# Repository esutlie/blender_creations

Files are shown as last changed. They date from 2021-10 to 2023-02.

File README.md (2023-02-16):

<h3 align="center">Blender Creations</h3>
  <p align="center">
    Create custom 3D printed pieces for behavior boxes and headcap implants.
  </p>
</div>

<!-- ABOUT THE PROJECT -->
## About The Project

Create and export blender meshes for 3D printing. Headcap builds are for Neuropixel 2.0 probes. Assembly and surgury protocol for implantation in mice will be published in a future methods paper. Chamber builds are for the behavior boxes used in the Shuler lab.

<!-- GETTING STARTED -->
## Installation

1. Clone the repo
   ```sh
   git clone https://github.com/esutlie/blender_creations.git
   ```
2. Selecet pieces to generate in main.py (dimentions an be adjusted in builds.py)
3. Select call_file_win.py in the blender file viewer and click run

<!-- LICENSE -->
## License

Distributed under the MIT License. See `LICENSE.txt` for more information.

<!-- CONTACT -->
## Contact

Elissa Sutlief - elissasutlief@gmail.com

Project Link: [https://github.com/esutlie/behavior_code](https://github.com/esutlie/behavior_code)

<p align="right">(<a href="#readme-top">back to top</a>)</p>

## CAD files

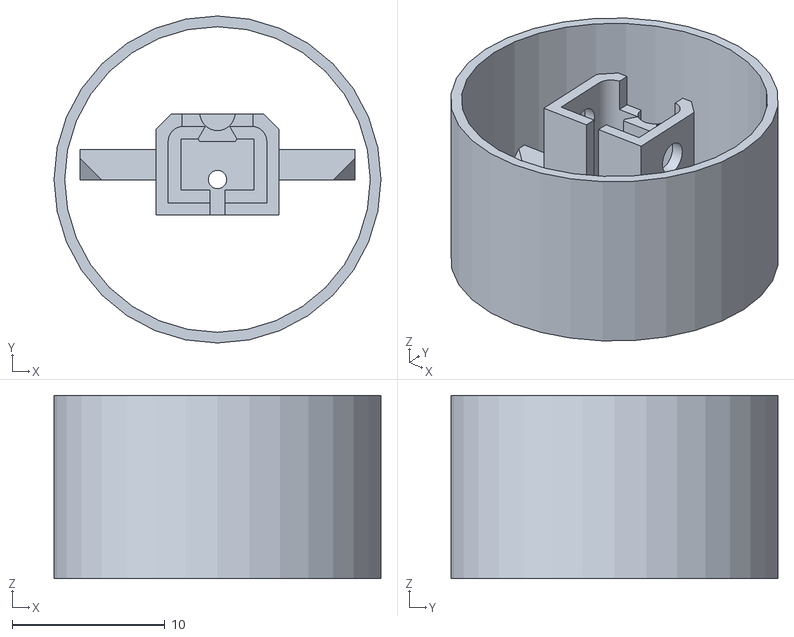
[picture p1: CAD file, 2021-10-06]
blender/stlexports/2021-09-28_10-52-53/cap.stl
21.4 x 21.4 x 12.0

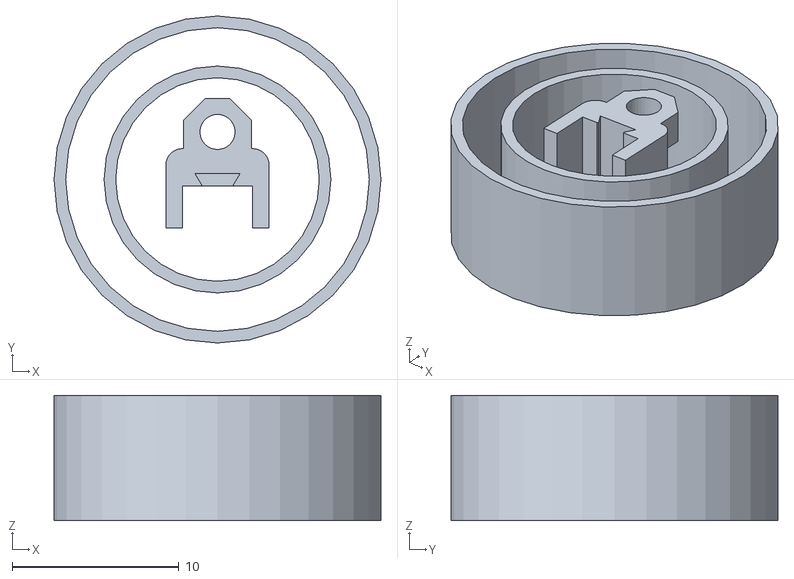
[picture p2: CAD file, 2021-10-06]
blender/stlexports/2021-09-29_13-45-59/holder.stl
19.6 x 19.6 x 7.50

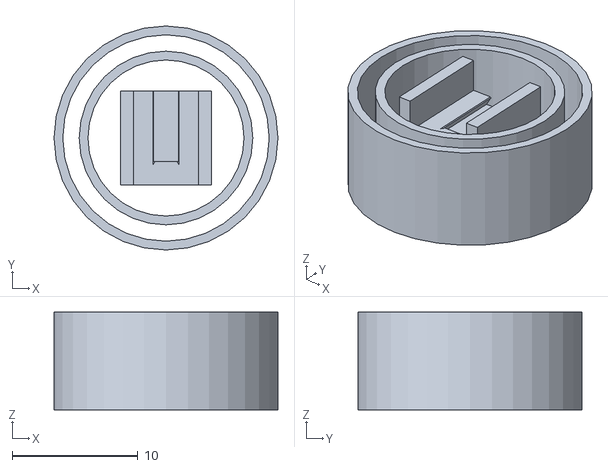
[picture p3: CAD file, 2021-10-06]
blender/stlexports/2021-09-30_14-25-20/holder.stl
17.8 x 17.8 x 7.75

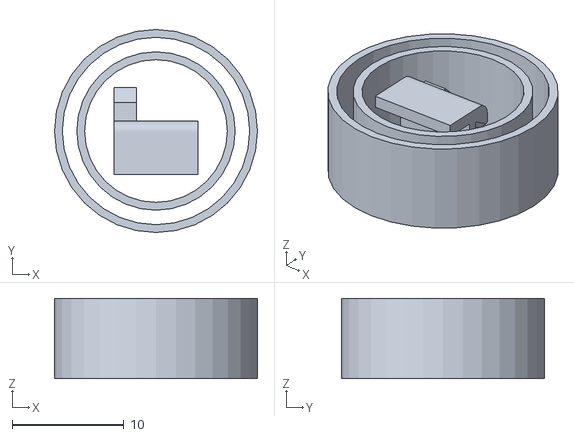
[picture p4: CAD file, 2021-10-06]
blender/stlexports/2021-09-30_14-29-47/holder.stl
18.2 x 18.2 x 7.20

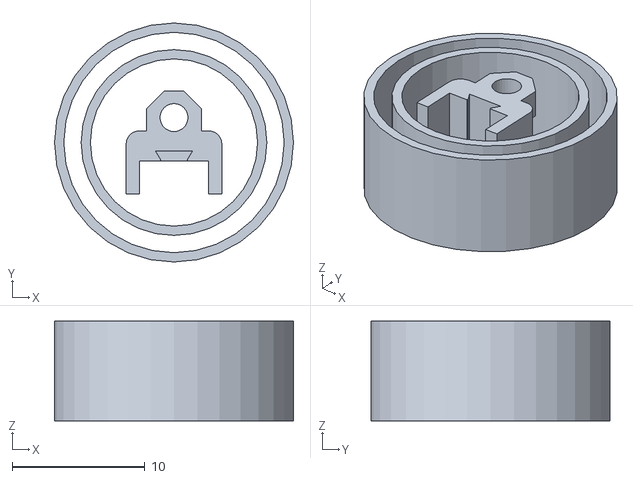
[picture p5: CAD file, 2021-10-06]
blender/stlexports/2021-09-30_14-30-03/holder.stl
18.0 x 18.0 x 7.50

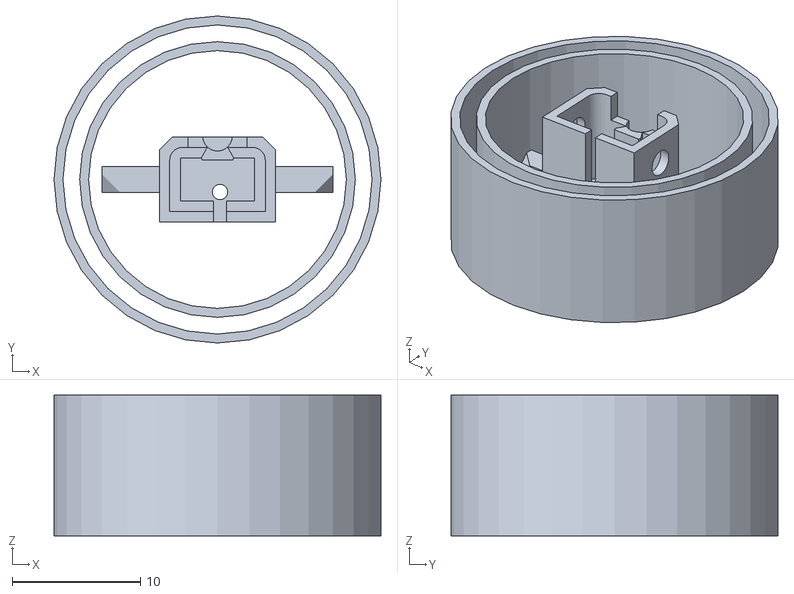
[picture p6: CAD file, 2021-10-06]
blender/stlexports/2021-10-01_13-02-37/cap.stl
25.5 x 25.5 x 11.0

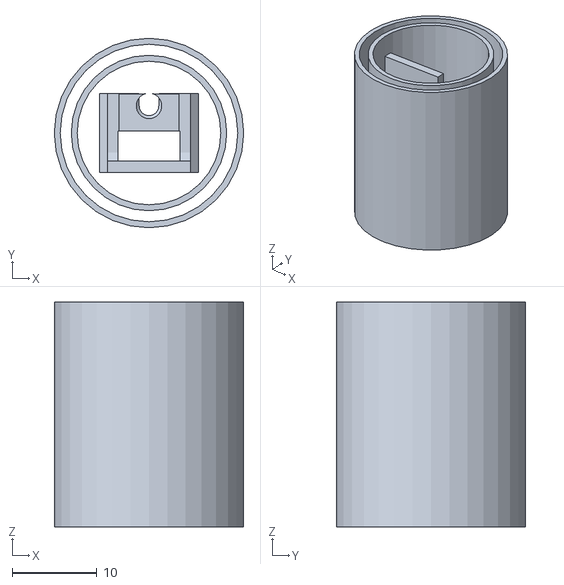
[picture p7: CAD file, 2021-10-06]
blender/stlexports/2021-10-04_15-12-39/cover.stl
22.3 x 22.3 x 26.5

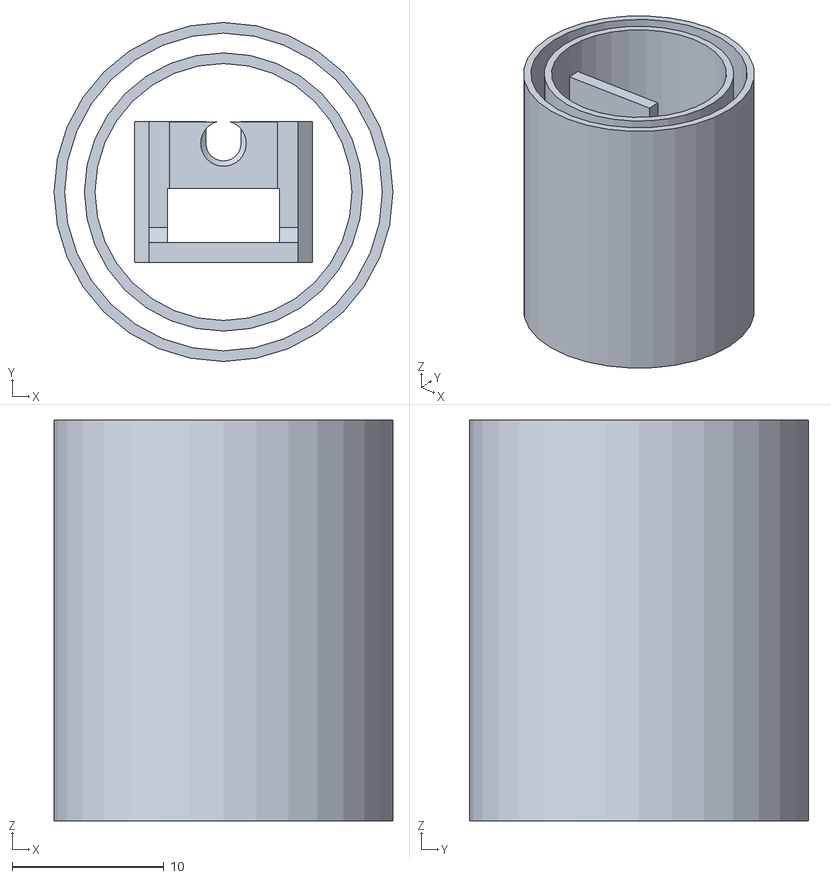
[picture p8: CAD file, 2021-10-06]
blender/stlexports/2021-10-05_10-55-50/cover.stl
22.3 x 22.3 x 26.4

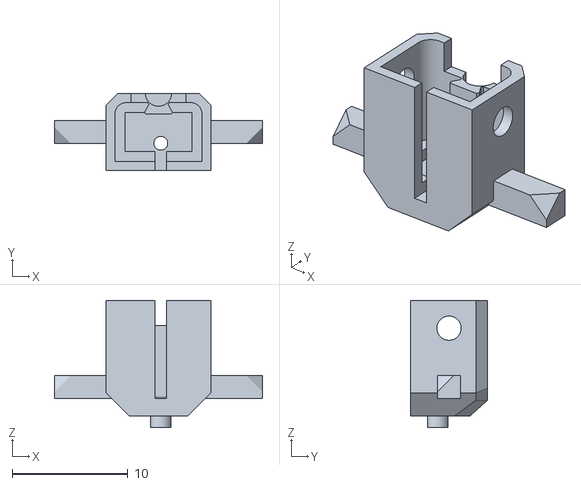
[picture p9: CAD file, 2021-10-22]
blender/stlexports/2021-10-06_15-07-09/cap0.17.stl
18.0 x 6.65 x 11.0

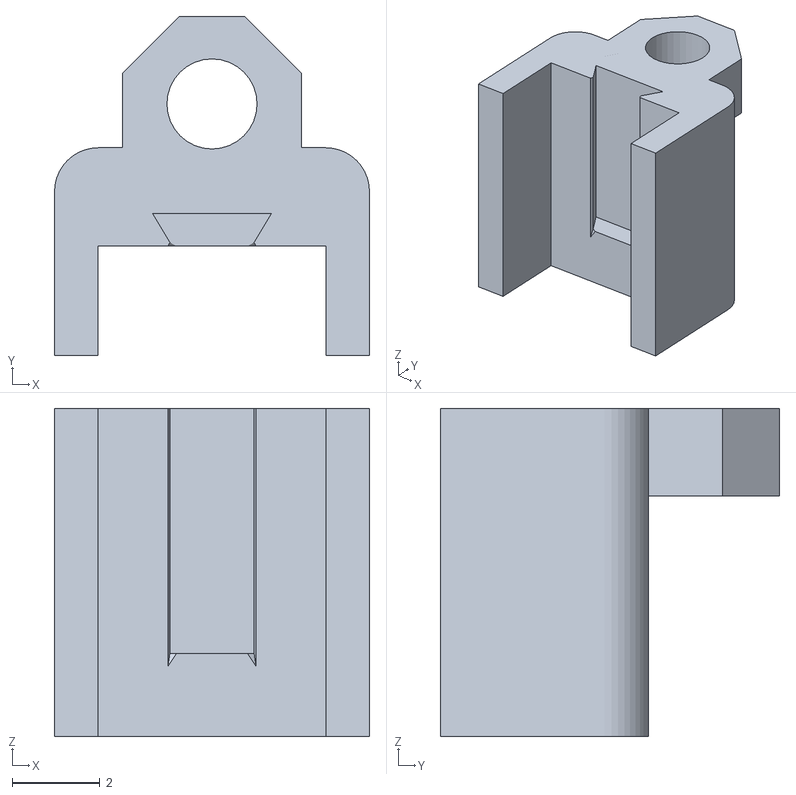
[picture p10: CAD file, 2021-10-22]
blender/stlexports/2021-10-06_15-36-01/holder2.72.stl
7.20 x 7.75 x 7.50

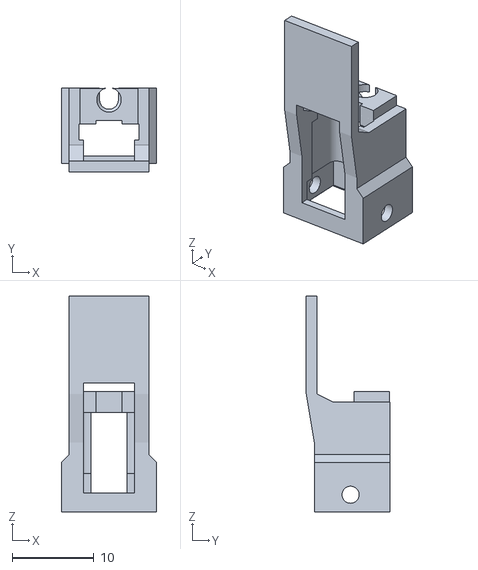
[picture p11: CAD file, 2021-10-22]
blender/stlexports/2021-10-08_12-12-51/cover.stl
11.7 x 10.2 x 26.5

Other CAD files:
blender/stlexports/2021-10-01_12-37-54/holder.stl
blender/stlexports/2021-10-05_10-56-01/cover.stl
blender/stlexports/2021-10-05_10-56-15/holder.stl
blender/stlexports/2021-10-06_12-04-05/holder2.74.stl
blender/stlexports/2021-10-06_15-03-10/cap0.155.stl
blender/stlexports/2021-10-07_14-12-16/holder.stl
blender/stlexports/2021-10-07_14-18-41/holder.stl
blender/creation.blend
blender/shichen_stereotax.blend
blender/stlexports/2021-09-14_11-30-54/cap.stl
blender/stlexports/2021-09-14_11-30-54/holder.stl
blender/stlexports/2021-09-27_09-42-36/cap.stl
blender/stlexports/2021-09-27_09-42-36/holder.stl
blender/stlexports/2021-09-27_13-36-47/cap.stl
blender/stlexports/2021-09-27_13-36-47/cover.stl
blender/stlexports/2021-09-27_13-36-47/holder.stl
blender/stlexports/2021-09-27_16-23-26/cap.stl
blender/stlexports/2021-09-27_16-23-26/cover.stl
blender/stlexports/2021-09-27_16-23-26/holder.stl
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

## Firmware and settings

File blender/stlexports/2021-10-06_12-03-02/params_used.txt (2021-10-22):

DOVE_ANGLE: 1.0297442586766543
DOVE_DEPTH: 0.75
DOVE_HEIGHT: 8.1
DOVE_INNER_WIDTH: 1.868709071458659
DOVE_OUTER_WIDTH: 2.77
DOVE_Z_SPACER: 0.5
DRIVER_WIDTH: 3
PIXEL_BOTTOM: [5, 1.5, 6]
PIXEL_PROBE: [0.75, 0.024, 10]
PIXEL_PROBE_Y: 0.4
PIXEL_TOP: [7, 1.6, 7]
PIXEL_X_OFFSET: 0.2
SCREWHEAD_DEPTH: 1
SCREWHEAD_LOWER_RADIUS: 1.15
SCREWHEAD_UPPER_RADIUS: 2.25
SCREW_LENGTH: 16
SCREW_THREAD_RADIUS: 1.05
add_shield: <bound method HeadMount2.add_shield of <builds.HeadMount2 object at 0x12c9fbc40>>
added_cleaner_space: 1
base_bevel: 0.5
base_thickness: 3
base_width: 30
bevel_offset: 1
bridge_thickness: 5
bridge_width: 10.3
bridge_y: 10
cap: <bound method HeadMount2.cap of <builds.HeadMount2 object at 0x12c9fbc40>>
cap_bottom_bevel: 2
cap_bottom_lip: 0.7
cap_bottom_thickness: 1.5
cap_clearance: 0.15
cap_size: [9.1, 6.65, 10.0]
cap_wall_thickness: 0.8
cap_window_base_thickness: 1.501
cap_window_width: 1
cleaner: <bound method HeadMount2.cleaner of <builds.HeadMount2 object at 0x12c9fbc40>>
cleaner_clearance: 0.35
cleaner_thickness: 1.5
cover: <bound method HeadMount2.cover of <builds.HeadMount2 object at 0x12c9fbc40>>
cover_clearance: 0.18
cover_holder_space: 7.5
cover_lip_depth: 1.5
cover_midsection_x: 5
cover_move_z: 12.23
cover_overhang: 4.7
cover_size: [11.7, 9.25, 13.5]
cover_squeezer_clearance: 0.7
cover_thickness: 1.3
cover_xyz: [0, 1.1550000000000002, 12.23]
dove2_clearance: 0.13
dove2_depth: 1
dove2_width: 2
dove_bevel: 0.2
eppendorf_height: 30
eppendorf_tube_diameter: 8
flex_space: 2
ground_cap_radius: 0.9
ground_inner_radius: 0.5
ground_outer_radius: 0.6
ground_pin_loc: [-2.5, -4.3, 0]
ground_wire_depth: 0.5
ground_wire_x: 1.5499999999999998
handle_size: [4.1, 4.5, 2]
head_fix_cylinder_radius: 0.7
head_fix_size: [18, 2, 2]
headfix: <bound method HeadMount2.headfix of <builds.HeadMount2 object at 0x12c9fbc40>>
headfix_bar_slant: 10
headfix_bar_z: 1.5
headfix_clearance: 0.4
headfix_inner_bevel: 2
headfix_outer_bevel: 2.1213203435596424
headfix_screw_radius: 1.1
headfix_thickness: 3
headstage_size: [17, 3, 12]
hex_depth: 2
hex_location: [0, 0.9750000000000001, 7.6]
hex_radius: 2.4
holder: <bound method HeadMount2.holder of <builds.HeadMount2 object at 0x12c9fbc40>>
holder_clearance: 0.1
holder_height: 7.5
holder_inner_wall_thickness: 0.5
holder_size: [7.2, 4.75, 7.5]
holder_space_below_dove: 2
holder_wall_thickness: 1
holder_xyz: [0, -1.4, 2.5]
holder_y_extension: 1
inset: 1
lip_height: 1
lip_inner_radius: 0.6
lip_outer_radius: 0.9
needle_diameter: 0.45
objects: [bpy.data.objects['holder2.77']]
pixel: <bound method HeadMount2.pixel of <builds.HeadMount2 object at 0x12c9fbc40>>
pixel_dove_bevel: 0.1
pixel_xyz: [0, 0, 4]
plug_depth: 2
plug_wall: 0.5
plug_width: 1
post_diameter: 0.82
protrusion: 5
screw_cover_location: [0, 4.35, 19.66]
screw_cover_size: [6.3, 4.75, 1]
screw_divot_depth: 0.5
screw_divot_radius: 1.1
screw_hole_radius: 0.6
screw_hole_x_offset: 6.7
screw_hole_z_offset: 7.5
screw_y: 4.35
screwhead_top: 0.35
secure_screw_location: [0, 0.9750000000000001, 7.6499999999999995]
shield_thickness: 0.7
squeeze_length: 15
squeezer_bottom_thickness: 2
squeezer_bump_size: 0.8
squeezer_handle_gap: 1
squeezer_handle_length: 14
squeezer_handle_size: [5, 100, 5]
squeezer_handle_thickness: 2
squeezer_rotate_center: 7
squeezer_thickness: 0.1
squeezer_width: 5
squeezer_z_shape: [1, 1.2, 1.2, 5]
stabber: <bound method HeadMount2.stabber of <builds.HeadMount2 object at 0x12c9fbc40>>
stand: <bound method HeadMount2.stand of <builds.HeadMount2 object at 0x12c9fbc40>>
stand_base_size: [75.7, 74.55, 3]
stand_clearance: 0.3
stand_cover_depth: 10
stand_extra_lower_distance: 2.5
stand_front: 3
stand_lid_size: [69.7, 68.55, 79.5]
stand_lid_thickness: 1
stand_ridge: 0.6
stand_size: [15.7, 17.55, 52.5]
stand_thickness: 2
stereotax_bar_length: 20
stereotax_bar_thickness: 4.3
stereotax_bevel: 1.4142135623730951
stereotax_width: 44
stopper: <bound method HeadMount2.stopper of <builds.HeadMount2 object at 0x12c9fbc40>>
surgery: <bound method HeadMount2.surgery of <builds.HeadMount2 object at 0x12c9fbc40>>
surgery_post_separation: 4
tracking_cylinder_radius: 2
tube: <bound method HeadMount2.tube of <builds.HeadMount2 object at 0x12c9fbc40>>
wire_location: [-1.5499999999999998, -3.3150000000000004, 5.0]

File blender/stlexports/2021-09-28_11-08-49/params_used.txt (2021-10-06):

angle_port: 0.7853981633974483
angle_side: 0.00017453292519943296
base: <bound method Chamber.base of <builds.Chamber object at 0x129b2c2b0>>
base_back_factor: 1.02
base_back_thickness: 0.451
base_points: [[1.2375735931288072, -0.03], [2.9877669528906634, -1.780193359761856], [2.987766922440219, -6.778338868492769], [3.3724724245309647, -7.256389591581498]]
build_ir: <bound method Chamber.build_ir of <builds.Chamber object at 0x129b2c2b0>>
c_port: 0.03
cable_cover: <bound method Chamber.cable_cover of <builds.Chamber object at 0x129b2c2b0>>
cable_location: [0, -0.5333333333333333, 4]
cable_radius: 0.8
cam_attach: <bound method Chamber.cam_attach of <builds.Chamber object at 0x129b2c2b0>>
cam_attach_depth: 0.5
cam_cover: <bound method Chamber.cam_cover of <builds.Chamber object at 0x129b2c2b0>>
cam_cover_diameter: 2.5
cam_hole_diameter: 3.5
cam_hole_location: [0, -3.3838834764831844, 4]
cam_lip_diameter: 4
center: [0.0, -3.0177669529663693]
clearance_base: 0.03
clearance_fastener: 0.023
cut_fastener_holes: <bound method Chamber.cut_fastener_holes of <builds.Chamber object at 0x129b2c2b0>>
cut_screw_holes: <bound method Chamber.cut_screw_holes of <builds.Chamber object at 0x129b2c2b0>>
external_points: [[1.5399494936611664, 0.7], [3.7177669529663686, -1.477817459305202], [3.7177669154387334, -7.63761534013078]]
extra_back_clearance: 0.03
eye_separation: 1.2
factor: 0.23195959492893317
fastener: <bound method Chamber.fastener of <builds.Chamber object at 0x129b2c2b0>>
fastener_multipliers: [1.3, 0.9, 0.5, 0.2]
fastener_x: 0.625
fastener_z: -0.75
frame: <bound method Chamber.frame of <builds.Chamber object at 0x129b2c2b0>>
frame2: <bound method Chamber.frame2 of <builds.Chamber object at 0x129b2c2b0>>
h_base: 0.5
h_bottom: 4.5
h_fastener: 0.44
h_locking: 3
h_top: 4
handle_length: 0.105
heights: [0.5, 4.5, 3, 4]
internal_points: [[1.25, 0], [3.017766952966369, -1.7677669529663687], [3.017766922504627, -6.767766876812014]]
objects: [bpy.data.objects['blank'], bpy.data.objects['port']]
overrider: {'active_annotation_layer': None, 'active_bone': None, 'active_editable_fcurve': None, 'active_gpencil_frame': None, 'active_gpencil_layer': None, 'active_object': None, 'active_operator': <bpy_struct, Operator("TEXT_OT_run_script") at 0x7fd6342b45a8>, 'active_pose_bone': None, 'annotation_data': None, 'annotation_data_owner': None, 'area': bpy.data.screens['Layout']...Area, 'blend_data': bpy.data.scenes['Scene']...BlendData, 'collection': bpy.data.collections['Collection'], 'edit_object': None, 'edit_text': bpy.data.texts['call_file_win.py'], 'editable_bones': None, 'editable_fcurves': None, 'editable_gpencil_layers': None, 'editable_gpencil_strokes': None, 'editable_objects': [], 'engine': 'BLENDER_EEVEE', 'evaluated_depsgraph_get': <bpy_func Context.evaluated_depsgraph_get()>, 'gizmo_group': None, 'gpencil_data': None, 'gpencil_data_owner': None, 'image_paint_object': None, 'layer_collection': bpy.data.scenes['Scene']...LayerCollection, 'mode': 'OBJECT', 'object': None, 'objects_in_mode': [], 'objects_in_mode_unique_data': [], 'particle_edit_object': None, 'pose_object': None, 'preferences': <bpy_struct, Preferences at 0x11c1c9060>, 'region': bpy.data.screens['Layout']...Region, 'region_data': None, 'scene': bpy.data.scenes['Scene'], 'screen': bpy.data.screens['Layout'], 'sculpt_object': None, 'selectable_objects': [], 'selected_bones': None, 'selected_editable_bones': None, 'selected_editable_fcurves': None, 'selected_editable_keyframes': None, 'selected_editable_objects': [], 'selected_editable_sequences': [], 'selected_nla_strips': None, 'selected_objects': [], 'selected_pose_bones': None, 'selected_pose_bones_from_active_object': None, 'selected_sequences': [], 'selected_visible_fcurves': None, 'sequences': [], 'space_data': bpy.data.screens['Layout']...SpaceView3D, 'tool_settings': bpy.data.scenes['Scene'].tool_settings, 'vertex_paint_object': None, 'view_layer': bpy.data.scenes['Scene'].view_layers["View Layer"], 'visible_bones': None, 'visible_fcurves': None, 'visible_gpencil_layers': None, 'visible_objects': [], 'visible_pose_bones': None, 'weight_paint_object': None, 'window': bpy.data.window_managers['WinMan']...Window, 'window_manager': bpy.data.window_managers['WinMan'], 'workspace': bpy.data.workspaces['Layout']}
place_fasteners: <bound method Chamber.place_fasteners of <builds.Chamber object at 0x129b2c2b0>>
port: <bound method Chamber.port of <builds.Chamber object at 0x129b2c2b0>>
segments: 2
thickness: 0.7
width_fastener: 0.22
width_port: 2.5
width_side: 5
x_inner_shifts: [1.25, 1.7677669529663689, -3.046174182401791e-08]
y_inner_shifts: [0, -1.7677669529663687, -4.999999923845645]

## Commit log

2021-09-28 edited np2 headcap
    [cap.stl, cover.stl, holder.stl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]
2021-09-28 fixed up the chamber
    [creation.blend]
2022-01-04 lots of edits to cap
    [backer.stl, base.stl, blank.stl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]
2022-02-21 changed the stopper to go in further, increased cover flex space, widened the cap window
    [cleaner.stl, params_used.txt]
2022-09-09 lots of changes
    [_params_used.txt, base_tictac.stl, cap-0.01.stl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]
2022-09-28 removed stl exports from git
2023-02-16 added option to have no floor on the chamber
    [creation.blend]
2023-02-22 small fixes and cleaning up the code. Added a zipped file containing all of the pieces for the neuropixel 2.0 assembly system
